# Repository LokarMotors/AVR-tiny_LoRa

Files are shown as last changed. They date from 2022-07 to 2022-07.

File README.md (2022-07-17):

# AVR-tiny_LoRa
# LoRaWAN node based on ATTiny87/167 and RFM95 #

Small LoRaWAN node with a temperature, air pressure and soil moisture sensor. Code includes modified Adafruit BMP180, LoRaWAN, RFM95 and custom Cayenne libraries to save flash. Circuit in made in EAGLE and includes a few avr circuit design considerations. ATTiny chip is programmed via ISP pins. Measured current consumption in deep sleep is 5μA at 3.3V and drops down to 3.9μA at 1.8V. Wake current consumption is 96.4mA at 3.3V and 79.5mA at 1.8V. Because of the RFM95 transmitter the maximum voltage is capped at 3.7V and the system is supplied with two AA batteries. According to simulations i made in Matlab the system could for 8 years in normal temperature conditions and uplinks every 30min. If there is a possibility to switch the RFM95 for a transmitter that is 5V tolerant the life expectancy of the device would be around 12 years with the same conditions with three AA batteries. Battery life is also affected by the spreading factor, table below shows wake time and battery life vs spreading factor.  

## Spread factor table (125k bandwith)

| Spreading factor  | Wake time | Battery life |
| --- | --- | --- |
| SF7 | 61 ms | 8.9 years |
| SF8 | 61 ms | 8.9 years |
| SF9 | 208 ms | 8.6 years |
| SF10 | 411 ms | 7.8 years |
| SF11 | 823 ms | 6.2 years |
| SF12 | 1483 ms | 4.2 years |

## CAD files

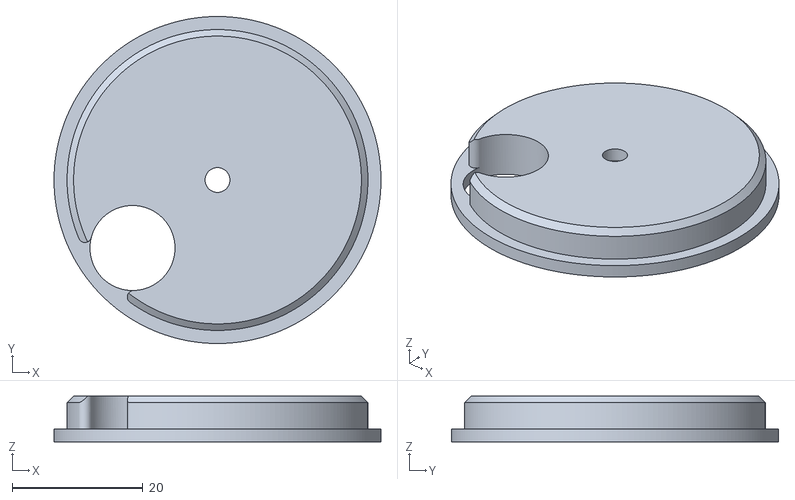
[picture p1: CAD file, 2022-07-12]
Models/Top.stl
50.0 x 50.0 x 7.00

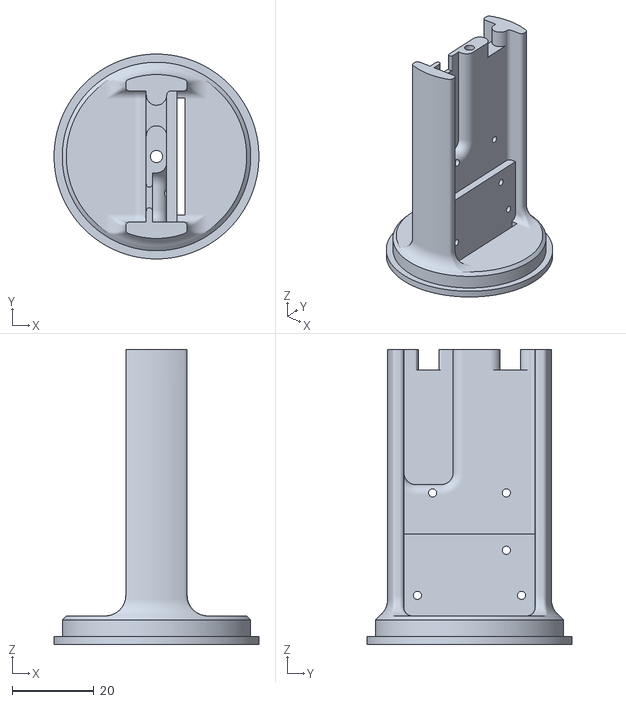
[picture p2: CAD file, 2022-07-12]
Models/Back_plate.stl
50.0 x 50.0 x 72.0

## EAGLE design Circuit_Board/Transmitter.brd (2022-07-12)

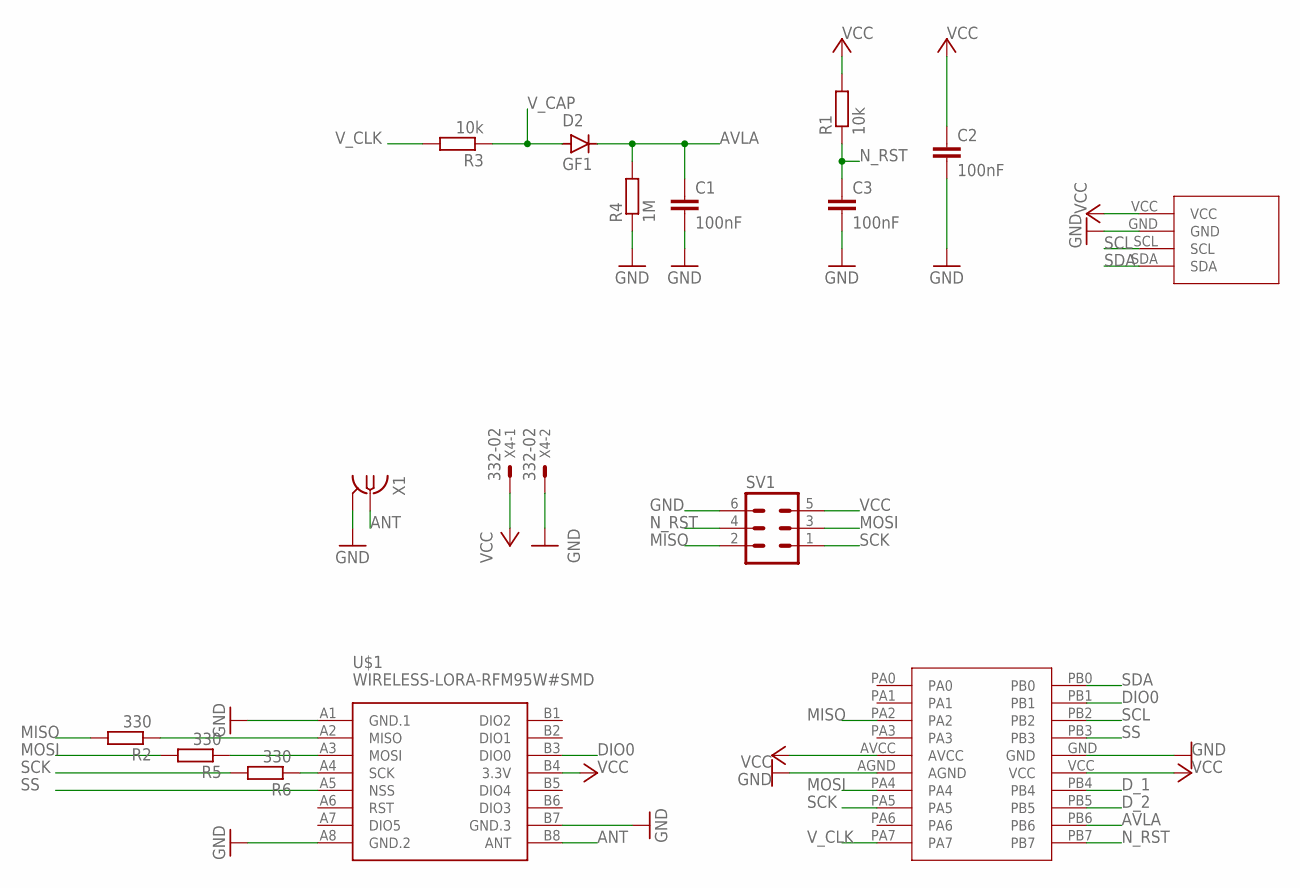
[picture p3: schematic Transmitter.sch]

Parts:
ATTINY87_1: ATTINY87_SOIC; 20-SOIC
C1, C2, C3: 100nF; C1206
D2: GF1; SMA-DO214AC
GY-68-1: GY-68-4
R1, R3: 10k; R0805
R2, R5, R6: 330; R0805
R4: 1M; R0805
SV1: MA03-2
U$1: WIRELESS-LORA-RFM95W#SMD
X1: BU-SMA-G
X4: 332-02

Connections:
ANT: U$1.B8 (ANT), X1.1
AVLA: ATTINY87_1.PB6, C1.1, D2.K (C), R4.2
DIO0: ATTINY87_1.PB1, U$1.B3 (DIO0)
D_1: ATTINY87_1.PB4
D_2: ATTINY87_1.PB5
GND: ATTINY87_1.AGND, ATTINY87_1.GND, C1.2, C2.2, C3.2, GY-68-1.GND, R4.1, SV1.6, U$1.A1 (GND.1), U$1.A8 (GND.2), U$1.B7 (GND.3), X1.2, X1.3 (2), X1.4 (2), X1.5 (2), X4.2
MISO: ATTINY87_1.PA2, R2.2, SV1.2
MOSI: ATTINY87_1.PA4, R5.2, SV1.3
unnamed: R2.1, U$1.A2 (MISO)
unnamed: R5.1, U$1.A3 (MOSI)
unnamed: R6.1, U$1.A4 (SCK)
N_RST: ATTINY87_1.PB7, C3.1, R1.1, SV1.4
SCK: ATTINY87_1.PA5, R6.2, SV1.1
SCL: ATTINY87_1.PB2, GY-68-1.SCL
SDA: ATTINY87_1.PB0, GY-68-1.SDA
SS: ATTINY87_1.PB3, U$1.A5 (NSS)
VCC: ATTINY87_1.AVCC, ATTINY87_1.VCC, C2.1, GY-68-1.VCC, R1.2, SV1.5, U$1.B4 (3.3V), X4.1
V_CAP: D2.A, R3.1
V_CLK: ATTINY87_1.PA7, R3.2

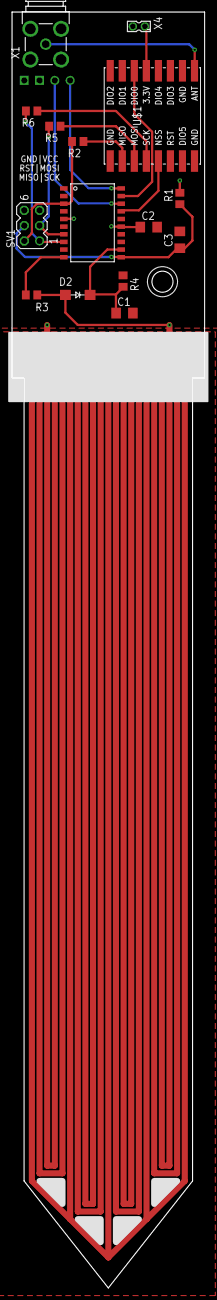
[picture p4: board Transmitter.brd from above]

Board: 2 copper layers, 32.0 x 212.0 mm, 16 parts (1 on the bottom side), 17 nets.

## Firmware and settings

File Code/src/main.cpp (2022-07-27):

#include <Arduino.h>
#include <avr/sleep.h>
#include <avr/wdt.h>
#include <avr/io.h>
#include <LoRaWAN.h>
#include <CAY_DIY.h>
#include <Adafruit_BMP085.h>
#include "config.h"

// RFM95 pins
#define DIO0 9
#define NSS 11

#define SLEEP_TIME 180 // ~10s per cycle 180 ----> 30min

// SOIL MOISTURE pins
#define V_CLK 7 // CLOCK pin
#define AVLA 14 // ANALOG pin ADC9

// SOIL MOISTURE SENSOR SETTINGS:
#define MOIST_W 179 // WET
#define MOIST_D 222 // DRY
#define MAX_3V3 228 // MAX ANALOG VALUE AT 3.3 volts

#ifndef cbi
#define cbi(sfr, bit) (_SFR_BYTE(sfr) &= ~_BV(bit))
#endif
#ifndef sbi
#define sbi(sfr, bit) (_SFR_BYTE(sfr) |= _BV(bit))
#endif

RFM95 rfm(DIO0, NSS);
LoRaWAN lora = LoRaWAN(rfm);
uint16_t Frame_Counter_Tx = 0x0000;

// Global Variable to Track Deep Sleep
volatile uint16_t sleep_count = SLEEP_TIME; // Send first message at power on

// Custom CAYENNE library
CAYDIY cayenne(3);

// Modified Adafruit BMP180 library
Adafruit_BMP085 sensor;
int16_t dry, wet;

void goToSleep();
int16_t GetMoisture();

void setup()
{
  lora.setKeys(NwkSkey, AppSkey, DevAddr);
  rfm.init();
  rfm.RFM_Set_Datarate(SF10BW125);
}

void loop()
{
  if (sleep_count >= SLEEP_TIME)
  {
    ADCSRA |= (1 << ADEN); // Enable ADC
    pinMode(V_CLK, OUTPUT);
    digitalWrite(V_CLK, LOW); // Discharging soil moisture capacitor
    if (sensor.begin(BMP085_ULTRALOWPOWER))
    {
      cayenne.Index = 0;
      cayenne.Add(0x01, 0x73, sensor.readPressure() / 10);
      // Saving space instead of calling sensor.readTemperature();
      int32_t X1 = (sensor.readRawTemperature() - (int32_t)sensor.ac6) * (int32_t)sensor.ac5 >> 15;
      int32_t X2 = ((int32_t)sensor.mc << 11) / (X1 + (int32_t)sensor.md);
      ///////////////////////////////////
      cayenne.Add(0x02, 0x67, (((X1 + X2 + 8) >> 4)));
      cayenne.Add(0x03, 0x02, map(GetMoisture(), MOIST_D, MOIST_W, 0, 10000));
    }
    lora.Send_Data(cayenne.Buffer, cayenne.Index, ++Frame_Counter_Tx);
    sleep_count = 0;
  }
  goToSleep();
}

void goToSleep()
{
  // Disable ADC, saves ~230uA
  ADCSRA &= ~(1 << ADEN);

  // setup watchdog "9" -> 8 sec
  MCUSR &= ~(1 << WDRF);
  WDTCR |= (1 << WDCE) | (1 << WDE);
  WDTCR = (9 & 7) | (1 << 5) | (1 << WDCE);
  WDTCR |= _BV(WDIE);
  ///////////////////////////////////

  set_sleep_mode(SLEEP_MODE_PWR_DOWN);
  sleep_mode();
  wdt_disable();
}

ISR(WDT_vect)
{
  sleep_count++; // keep track of how many sleep cycles have been completed.
}

int16_t GetMoisture()
{
  ADMUX &= 0b11000000; // clear last six bits
  ADMUX |= 0b00101001; // ADC9 and left adjust resaults for only 8-bit reading

  for (uint8_t i = 0; i < 255; i++)
  {
    ADCSRA |= (1 << ADSC); // first few measurements are not reliable
    delayMicroseconds(1);
    digitalWrite(V_CLK, HIGH);
    delayMicroseconds(1);
    digitalWrite(V_CLK, LOW);
  }
  ADCSRA |= (1 << ADSC);        // start conversion
  while (!(ADCSRA & 1 << ADIF)) // wait for conversion to finish
    ;
  int16_t out = (int16_t)ADCH;

  // compensation for battery discharge
  digitalWrite(V_CLK, HIGH);
  delay(15);
  ADCSRA |= (1 << ADSC);        // measure high voltage
  while (!(ADCSRA & 1 << ADIF)) // wait for conversion to finish
    ;
  out += (int16_t)(MAX_3V3 - ADCH); // compensate battery discharge
  digitalWrite(V_CLK, LOW);
  ///////////////////////////////////

  return out;
}

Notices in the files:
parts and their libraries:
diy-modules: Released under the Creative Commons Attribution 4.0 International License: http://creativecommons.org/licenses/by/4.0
